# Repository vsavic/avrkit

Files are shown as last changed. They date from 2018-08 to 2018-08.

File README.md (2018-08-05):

# Cycle Alpha - AVR Programmer Board - Quick Start Guide
**AVR-based microcontroller board, designed to help in small to medium production run**.

## Board Overview

This board is designed to be a portable, stand-alone programmer tool. We can store pre-compiled HEX files on SD card and burn them on new ATMega328 MCU.

Board supports DIP and SMD version of ATMega328 MCU via ZIF28 and TQFP32 sockets. Also there’s a direct ICSP line connected to these sockets via master \ slave jumper switch configuration.

Here’s a quick summary of some of the most important parts of the board:

1. SD Card
2. 5-Way Joystick
3. Button B
4. USB
5. Button A
6. 1.8” TFT Display
7. Power Jack
8. ICSP Header
9. Slave \ Master Selector
10. TQFP-32 SMT Socket
11. ZIF28 DIP Socket

Please refer to the image below to match the numbers with the coresponding components.

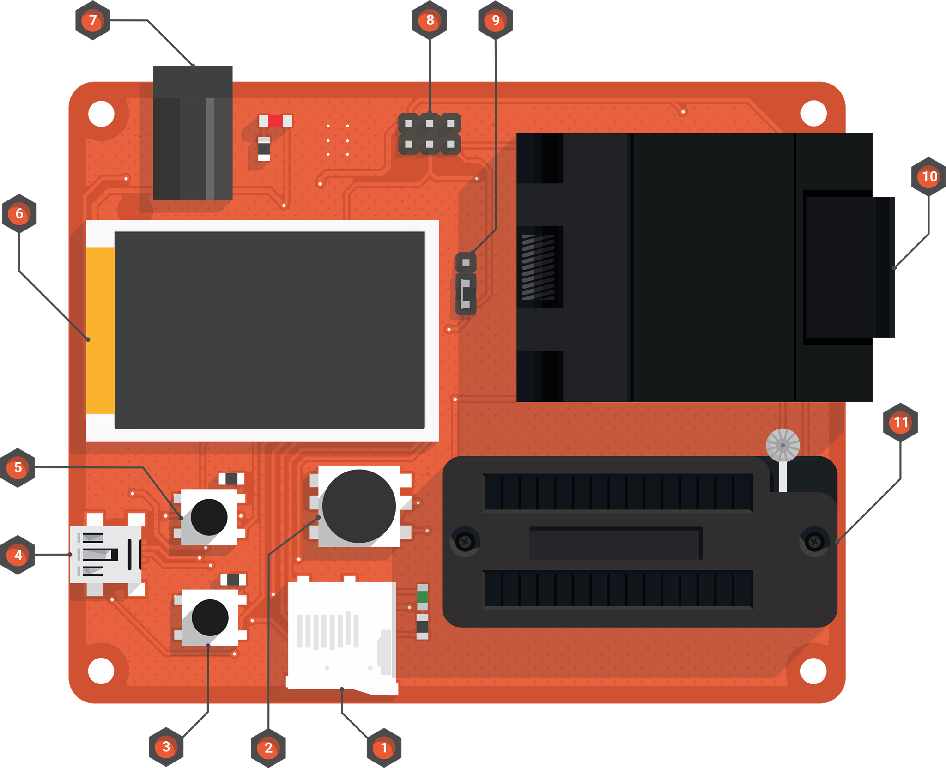
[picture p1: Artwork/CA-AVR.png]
Cycle Alpha - AVR Programmer Board


## Communcation
Board can be re-programmed via ICSP header, or directly via USB port.

It contains 1.8” TFT display which can be used with an on-board 5-way joystick in order to select the proper firmware which can be flashed on new MCU.

There’s also 2 additional buttons which are used to burn bootloader and to make a backup of the current code from the target MCU.

## Power
Board can be powered via USB cable or with external power supply battery connected to DC jack from 7 to 25 V DC. 

## Roadmap
* Add support to burn bootloader from EEPROM.
* Add support to store current target MCU firmware into EEPROM for further clonning.

At the moment, we can make a backup of the current firmware from target MCU by using "B" button on the board. Firmware will be stored on micro SD card as `Backup.hex` file.

## Notes
Common problem with some micro SD cards is that some of them cannot be initialized. In case that you get an serror screen with your SD card, follow the instruction. For more details, see `serial` console output.

SD card must be in FAT16 or FAT32 format in order to work with [SdFat](https://github.com/greiman/SdFat) library.

I tried a few different manufacturers, but the most reliable results I got with are with a Kingston 8GB class 10 micro SD card.

In case that you need to re-format your card, use this [SD Formatter](https://www.sdcard.org/downloads/formatter_4/index.html).

If you decide to modify the current firmware, keep in mind that SRAM is already very low.

Check this article for more details on [arduino memory problems](https://learn.adafruit.com/memories-of-an-arduino?view=all).

Also, here's one more really good article about [PROGMEM](http://www.gammon.com.au/progmem).

## Special Thanks

Special thanks to [Nick Gammon](https://www.gammon.com.au/contactus.htm), without him, his original project and amazing articles, this board wouldn't exist.

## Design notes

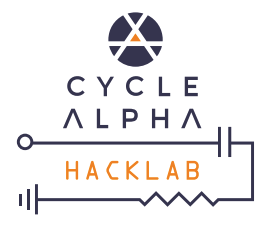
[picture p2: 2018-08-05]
Artwork/CA-HackLab.png

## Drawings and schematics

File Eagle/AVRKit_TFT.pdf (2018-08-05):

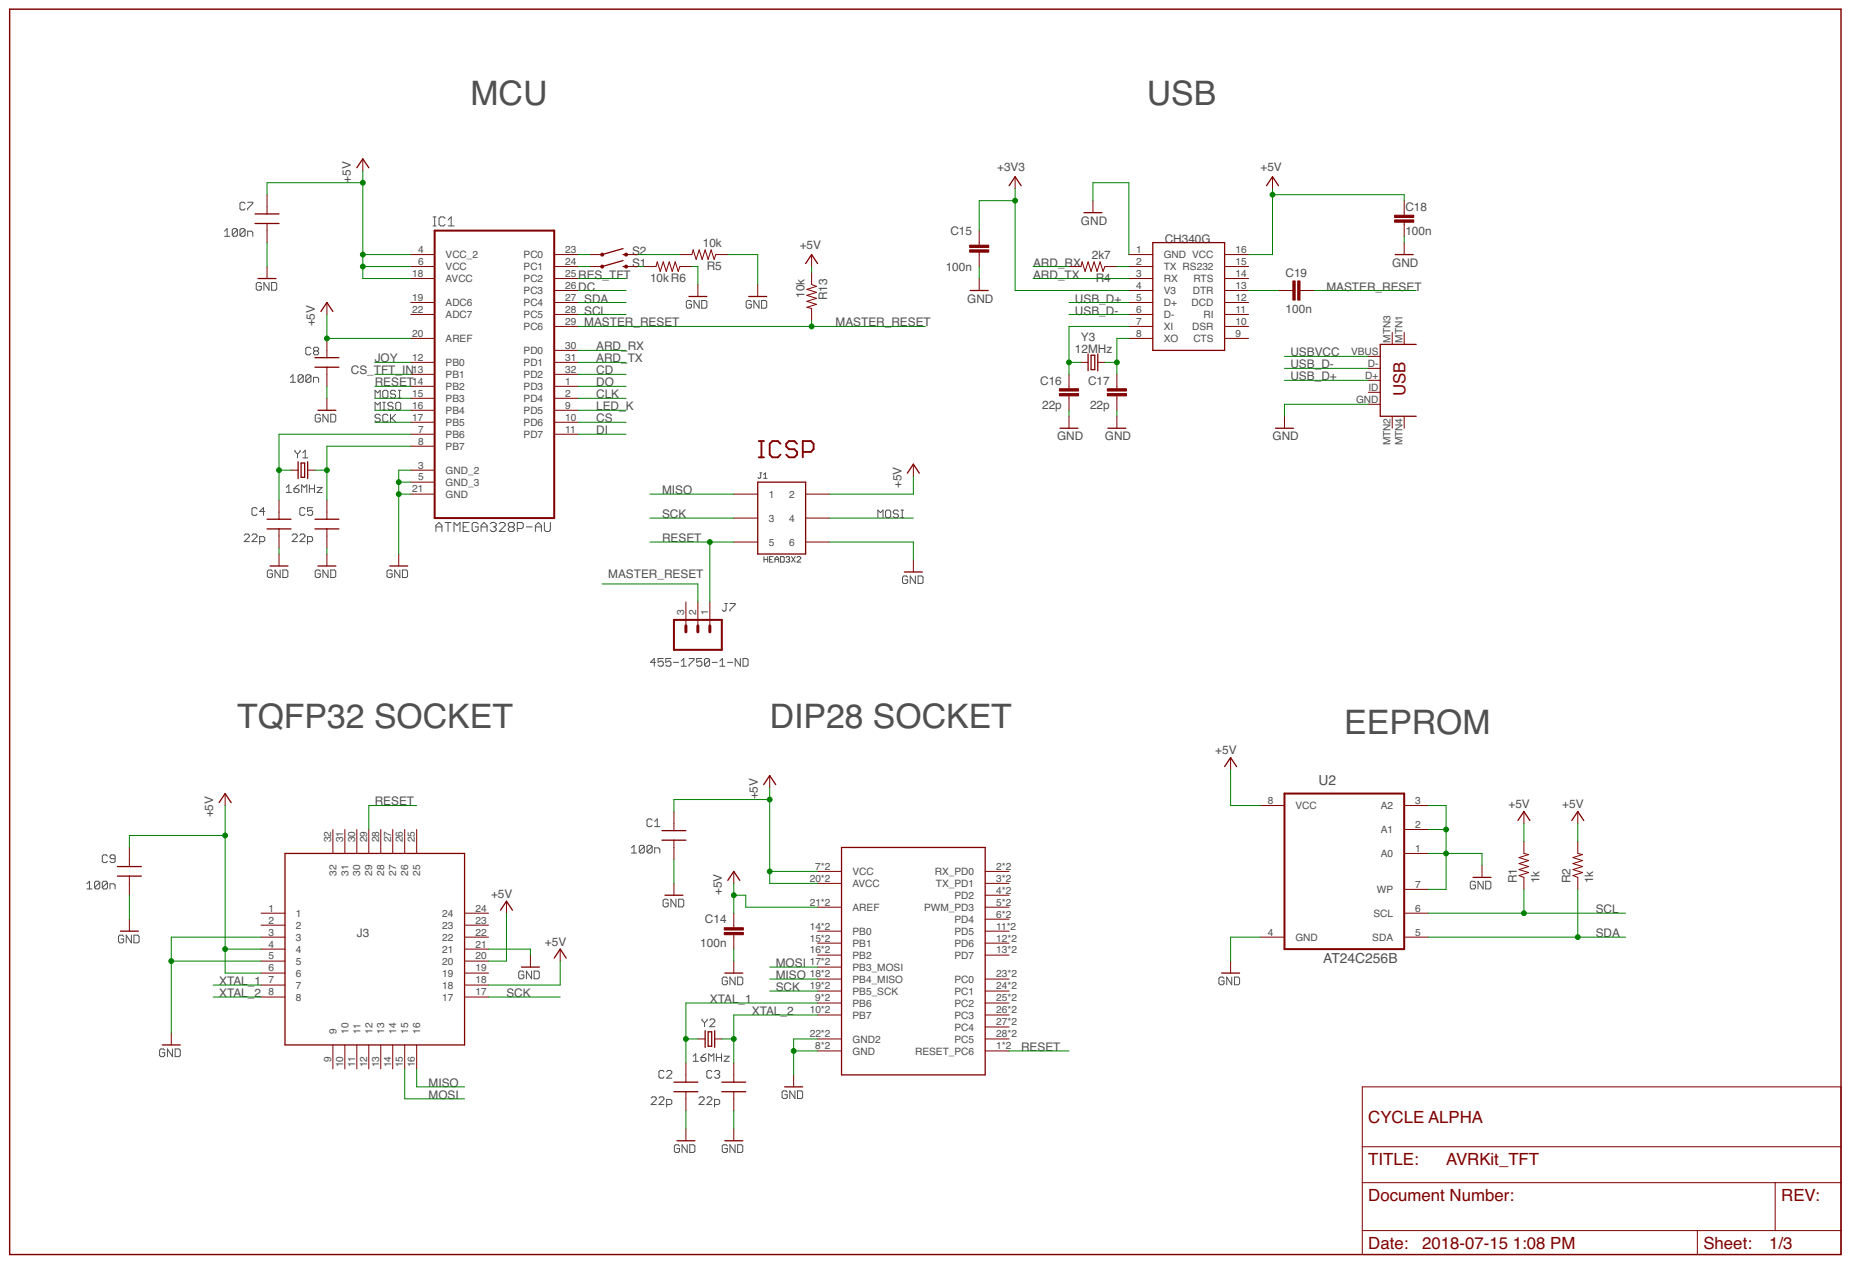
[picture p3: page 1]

REV: TITLE: Document Number: AVRKit_TFT

Date: 2018-07-15 1:08 PM | Sheet: 1/3

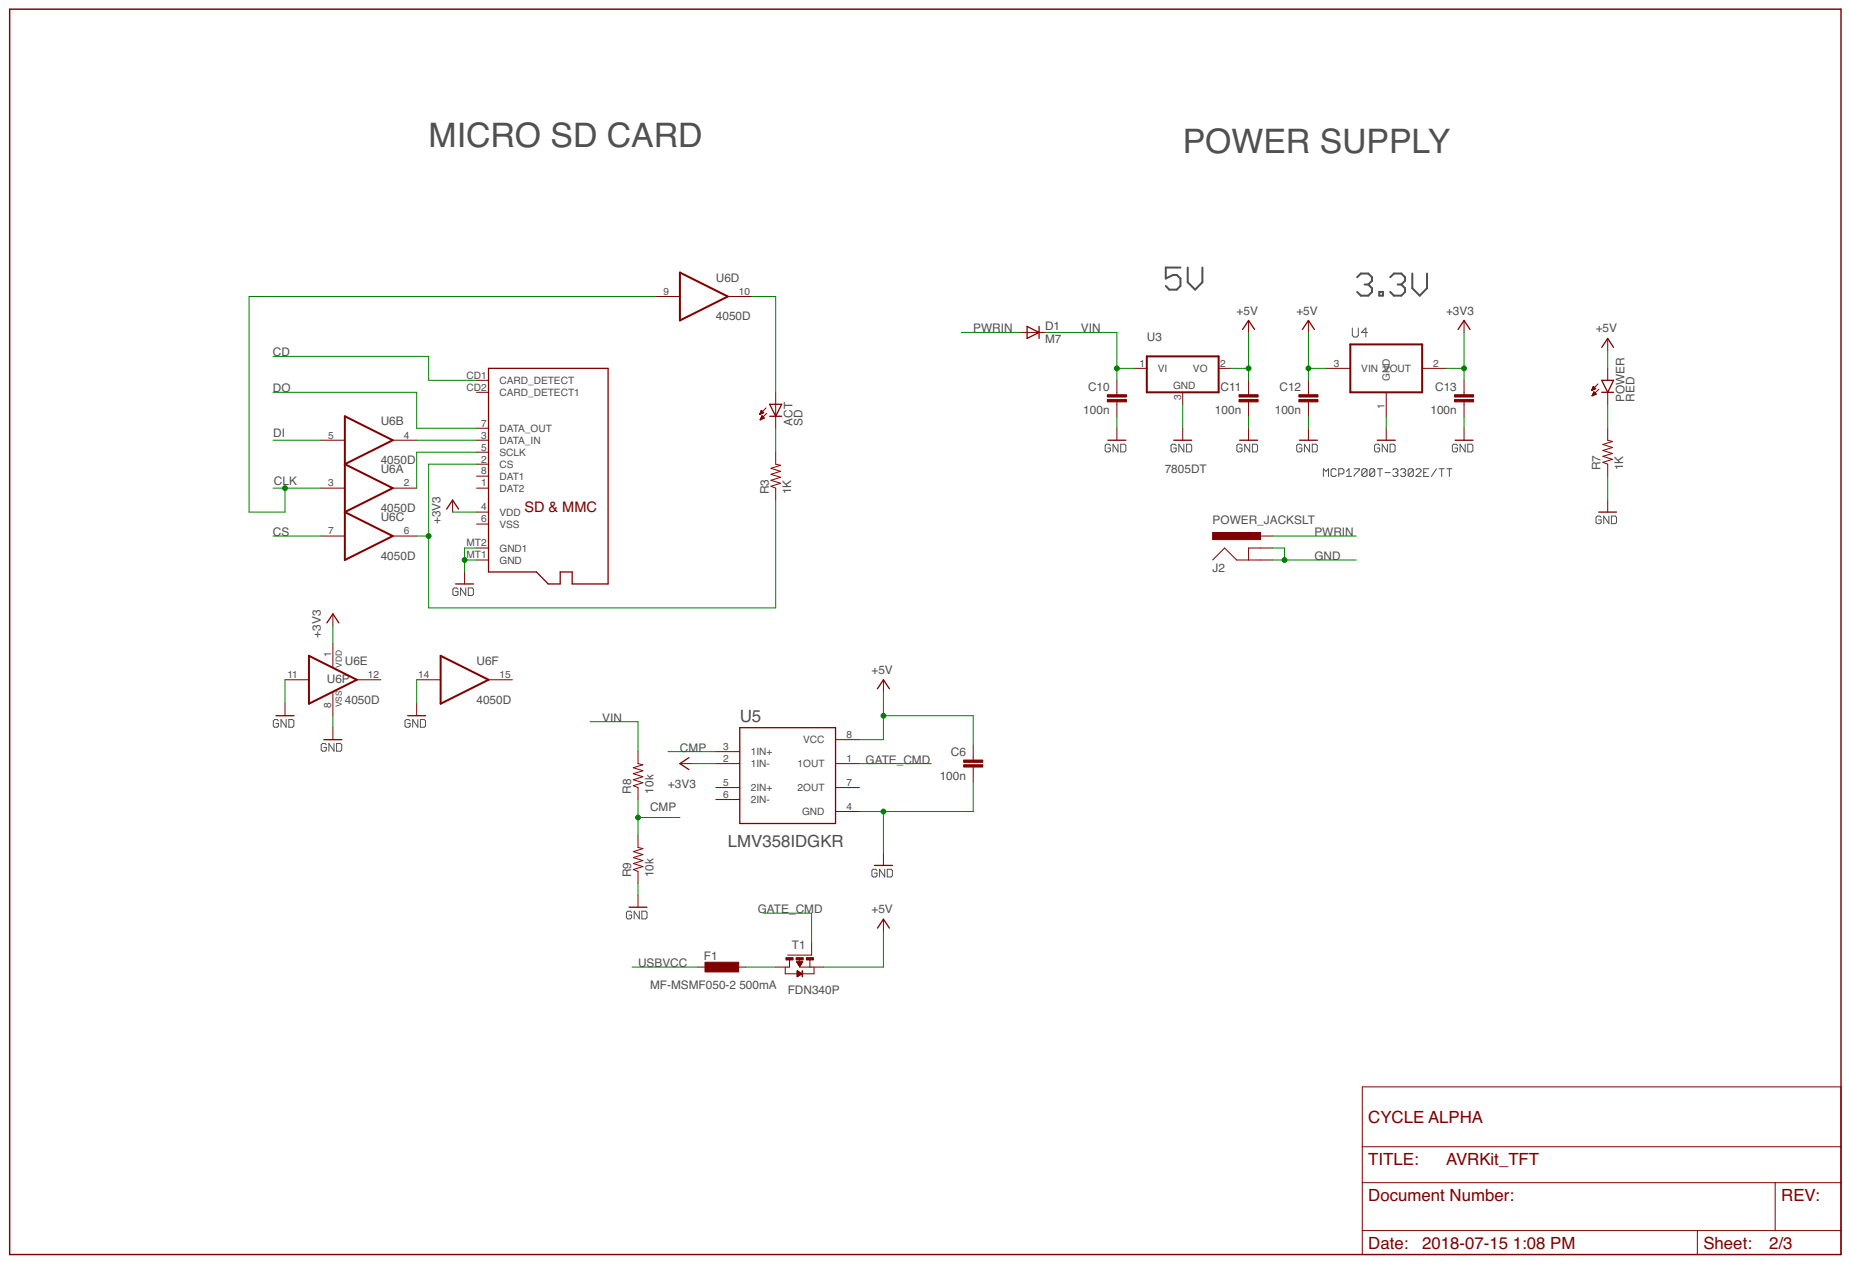
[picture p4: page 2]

REV: TITLE: Document Number: AVRKit_TFT

Date: 2018-07-15 1:08 PM | Sheet: 2/3

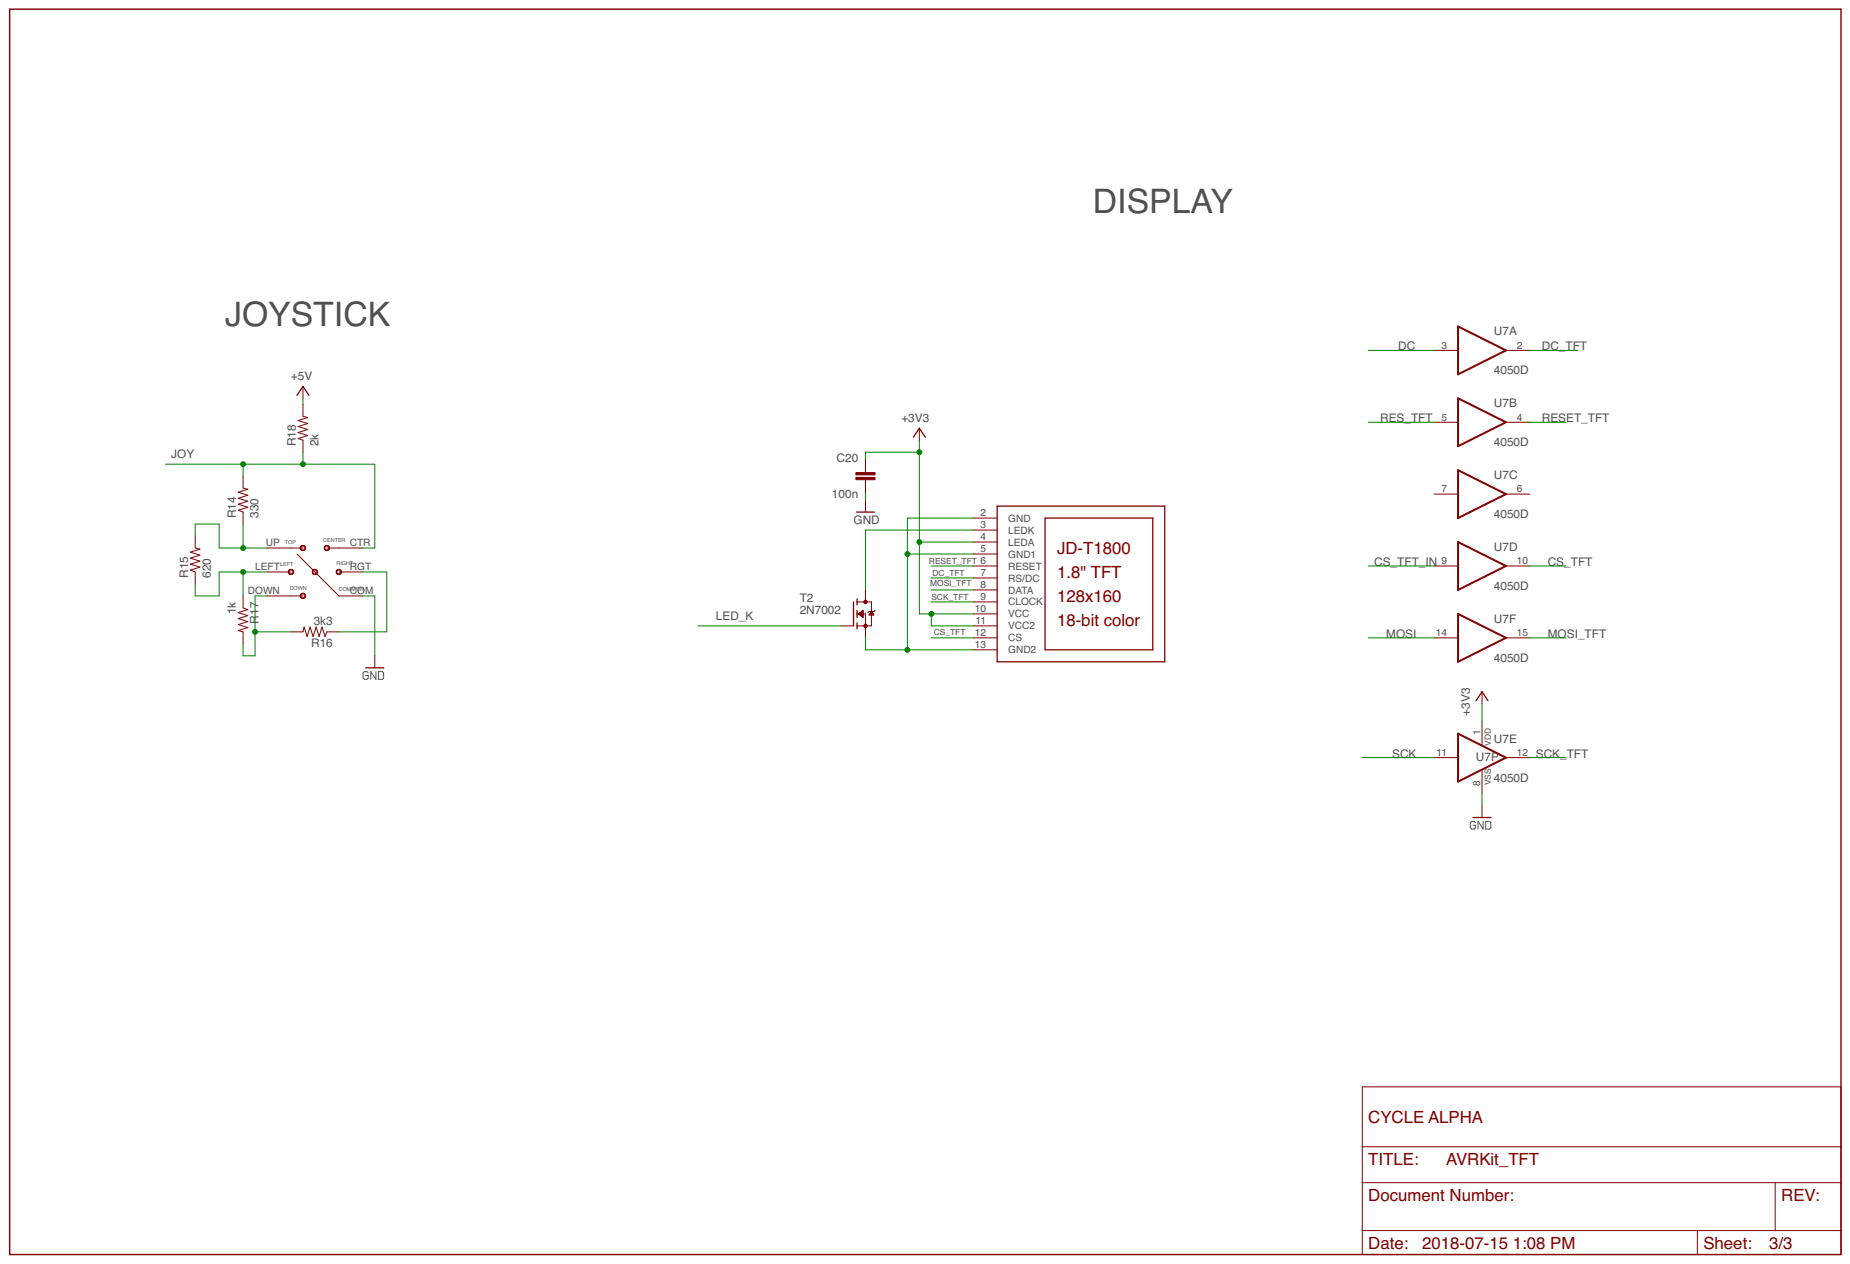
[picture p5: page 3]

REV: TITLE: Document Number: AVRKit_TFT

Date: 2018-07-15 1:08 PM | Sheet: 3/3

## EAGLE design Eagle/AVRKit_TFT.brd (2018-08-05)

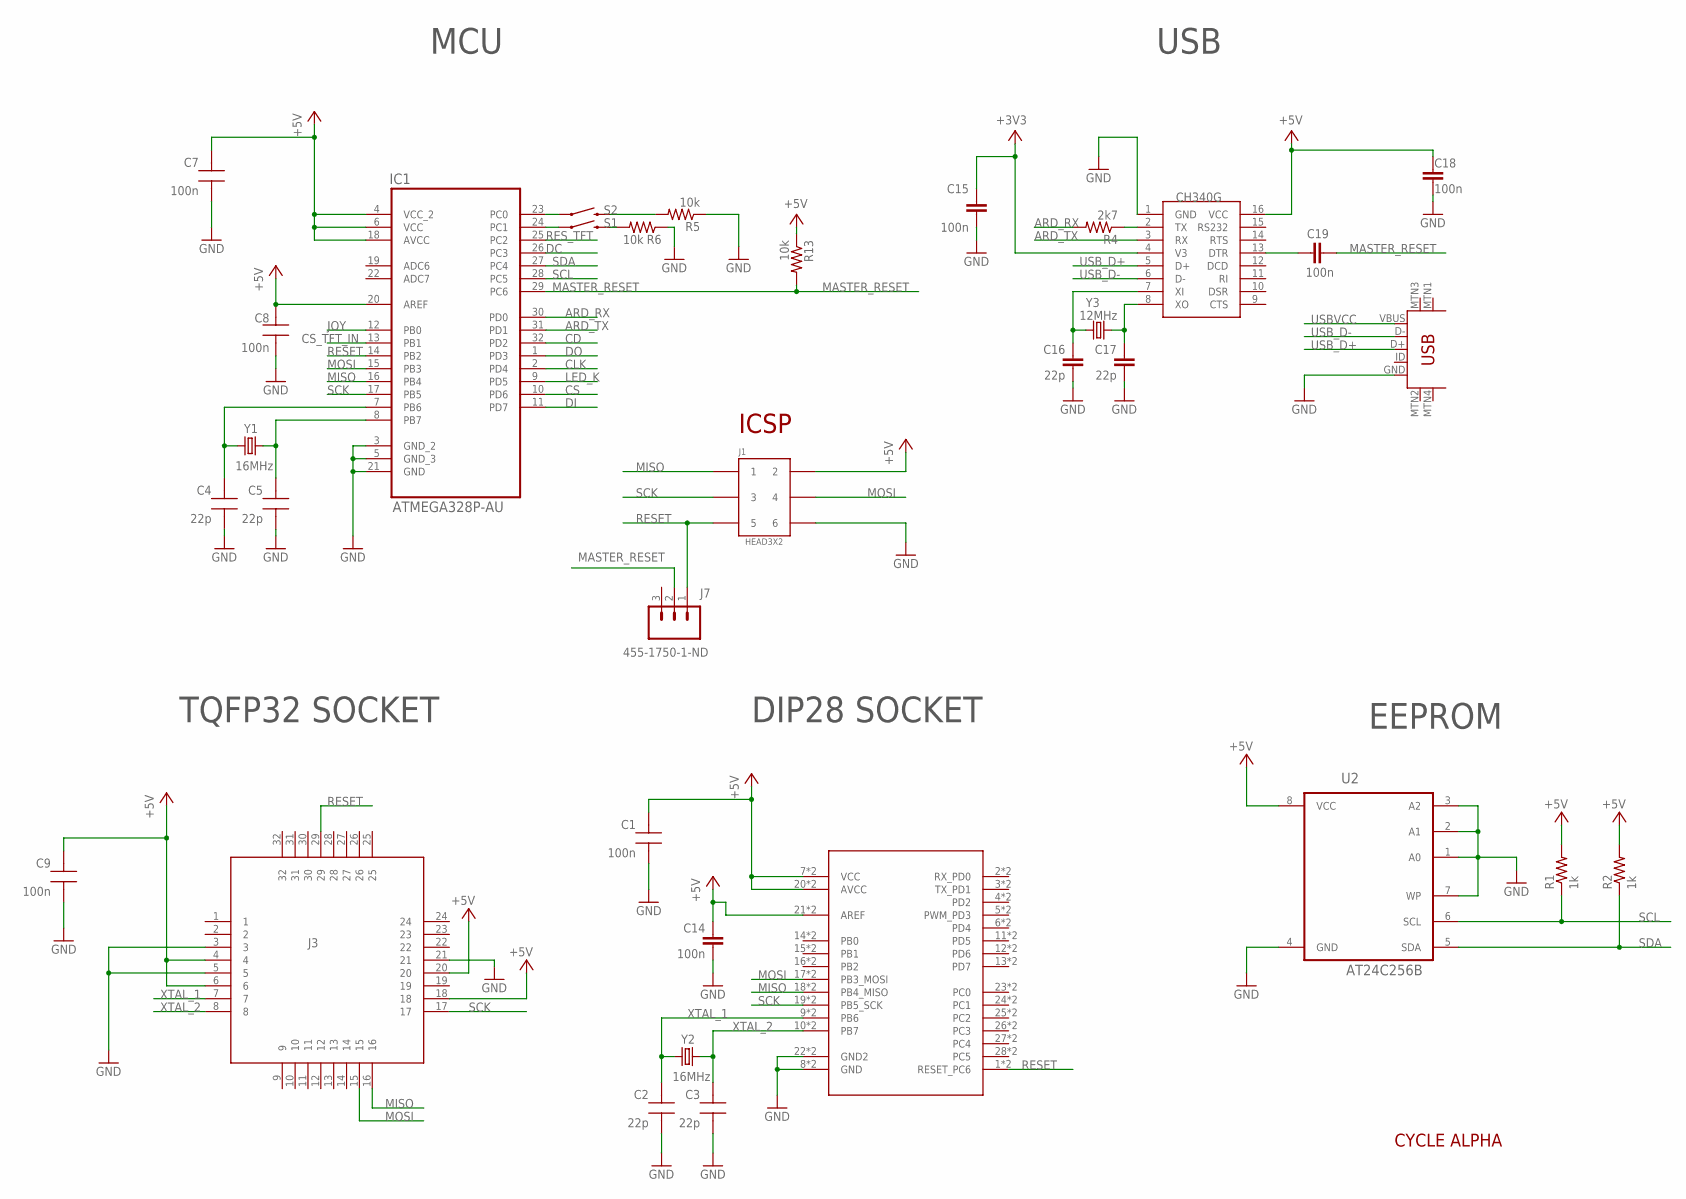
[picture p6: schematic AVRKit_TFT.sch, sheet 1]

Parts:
C1, C7, C8, C9: 100n; CAP0805-NP
C2, C3, C4, C5: 22p; CAP0805-NP
C14, C15, C18, C19: 100n; 0805
C16, C17: 22p; 0805
IC1: ATMEGA328P-AU; QFP80P900X900X120-32N
J1: HEAD3X2
J3: TQFP32_ADAPTER
J4: _ZIF28ADAPTER_2ROWS; DIL28_2ROWS
J5: USB-MINIB-5PIN; USB-MINIB
J7: 455-1750-1-ND; 1X03
R1, R2: 1k; R0805@1
R4: 2k7; R0805@1
R5, R6, R13: 10k; R0805@1
S1, S2: SWITCH-MOMENTARY-2SMD-4; TACTILE_SWITCH_TALL
U1: 0; SOIC16
U2: AT24C256B; SOIC8
Y1, Y2: 16MHz; CRYSTAL-SMD-5X3
Y3: 12MHz; CRYSTAL-SMD-5X3

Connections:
+3V3: C15.2, U1.4 (V3); also elsewhere on the board
+5V: C1.1, C7.1, C8.1, C9.1, C14.1, C18.2, IC1.4 (VCC_2), IC1.6 (VCC), IC1.18 (AVCC), IC1.20 (AREF), J1.2, J3.4, J3.6, J3.18, J3.20, J4.7 (VCC), J4.20 (AVCC), J4.21 (AREF), J4.107 (VCC), J4.120 (AVCC), J4.121 (AREF), R1.2, R2.2, R13.1, U1.16 (VCC), U2.8 (VCC); also elsewhere on the board
ARD_RX: IC1.30 (PD0), R4.2
ARD_TX: IC1.31 (PD1), U1.3 (RX)
CD: IC1.32 (PD2); also elsewhere on the board
CLK: IC1.2 (PD4); also elsewhere on the board
CS: IC1.10 (PD6); also elsewhere on the board
CS_TFT_IN: IC1.13 (PB1); also elsewhere on the board
DC: IC1.26 (PC3); also elsewhere on the board
DI: IC1.11 (PD7); also elsewhere on the board
DO: IC1.1 (PD3); also elsewhere on the board
GND: C1.2, C2.2, C3.2, C4.2, C5.2, C7.2, C8.2, C9.2, C14.2, C15.1, C16.2, C17.2, C18.1, IC1.3 (GND_2), IC1.5 (GND_3), IC1.21 (GND), J1.6, J3.3, J3.5, J3.21, J4.8 (GND), J4.22 (GND2), J4.108 (GND), J4.122 (GND2), J5.GND, R5.1, R6.1, U1.1 (GND), U2.1 (A0), U2.2 (A1), U2.3 (A2), U2.4 (GND), U2.7 (WP); also elsewhere on the board
JOY: IC1.12 (PB0); also elsewhere on the board
LED_K: IC1.9 (PD5); also elsewhere on the board
MASTER_RESET: C19.1, IC1.29 (PC6), J7.2, R13.2
MISO: IC1.16 (PB4), J1.1, J3.16, J4.18 (PB4_MISO), J4.118 (PB4_MISO)
MOSI: IC1.15 (PB3), J1.4, J3.15, J4.17 (PB3_MOSI), J4.117 (PB3_MOSI); also elsewhere on the board
unnamed: IC1.23 (PC0), S2.A2 (1)
unnamed: IC1.24 (PC1), S1.A2 (1)
unnamed: R5.2, S2.B2 (2)
unnamed: R6.2, S1.B2 (2)
unnamed: C19.2, U1.13 (DTR)
unnamed: R4.1, U1.2 (TX)
OSC3: C4.1, IC1.7 (PB6), Y1.3 (2)
OSC4: C5.1, IC1.8 (PB7), Y1.1
RESET: IC1.14 (PB2), J1.5, J3.29, J4.1 (RESET_PC6), J4.101 (RESET_PC6), J7.1
RES_TFT: IC1.25 (PC2); also elsewhere on the board
SCK: IC1.17 (PB5), J1.3, J3.17, J4.19 (PB5_SCK), J4.119 (PB5_SCK); also elsewhere on the board
SCL: IC1.28 (PC5), R1.1, U2.6 (SCL)
SDA: IC1.27 (PC4), R2.1, U2.5 (SDA)
USBVCC: J5.VBUS; also elsewhere on the board
USB_D+: J5.D+, U1.5 (D+)
USB_D-: J5.D-, U1.6 (D-)
XI1: C16.1, U1.7 (XI), Y3.1
XO1: C17.1, U1.8 (XO), Y3.3 (2)
XTAL_1: C2.1, J3.7, J4.9 (PB6), J4.109 (PB6), Y2.3 (2)
XTAL_2: C3.1, J3.8, J4.10 (PB7), J4.110 (PB7), Y2.1

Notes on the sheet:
USB
DIP28 SOCKET
MCU
EEPROM
TQFP32 SOCKET
ICSP
CYCLE ALPHA

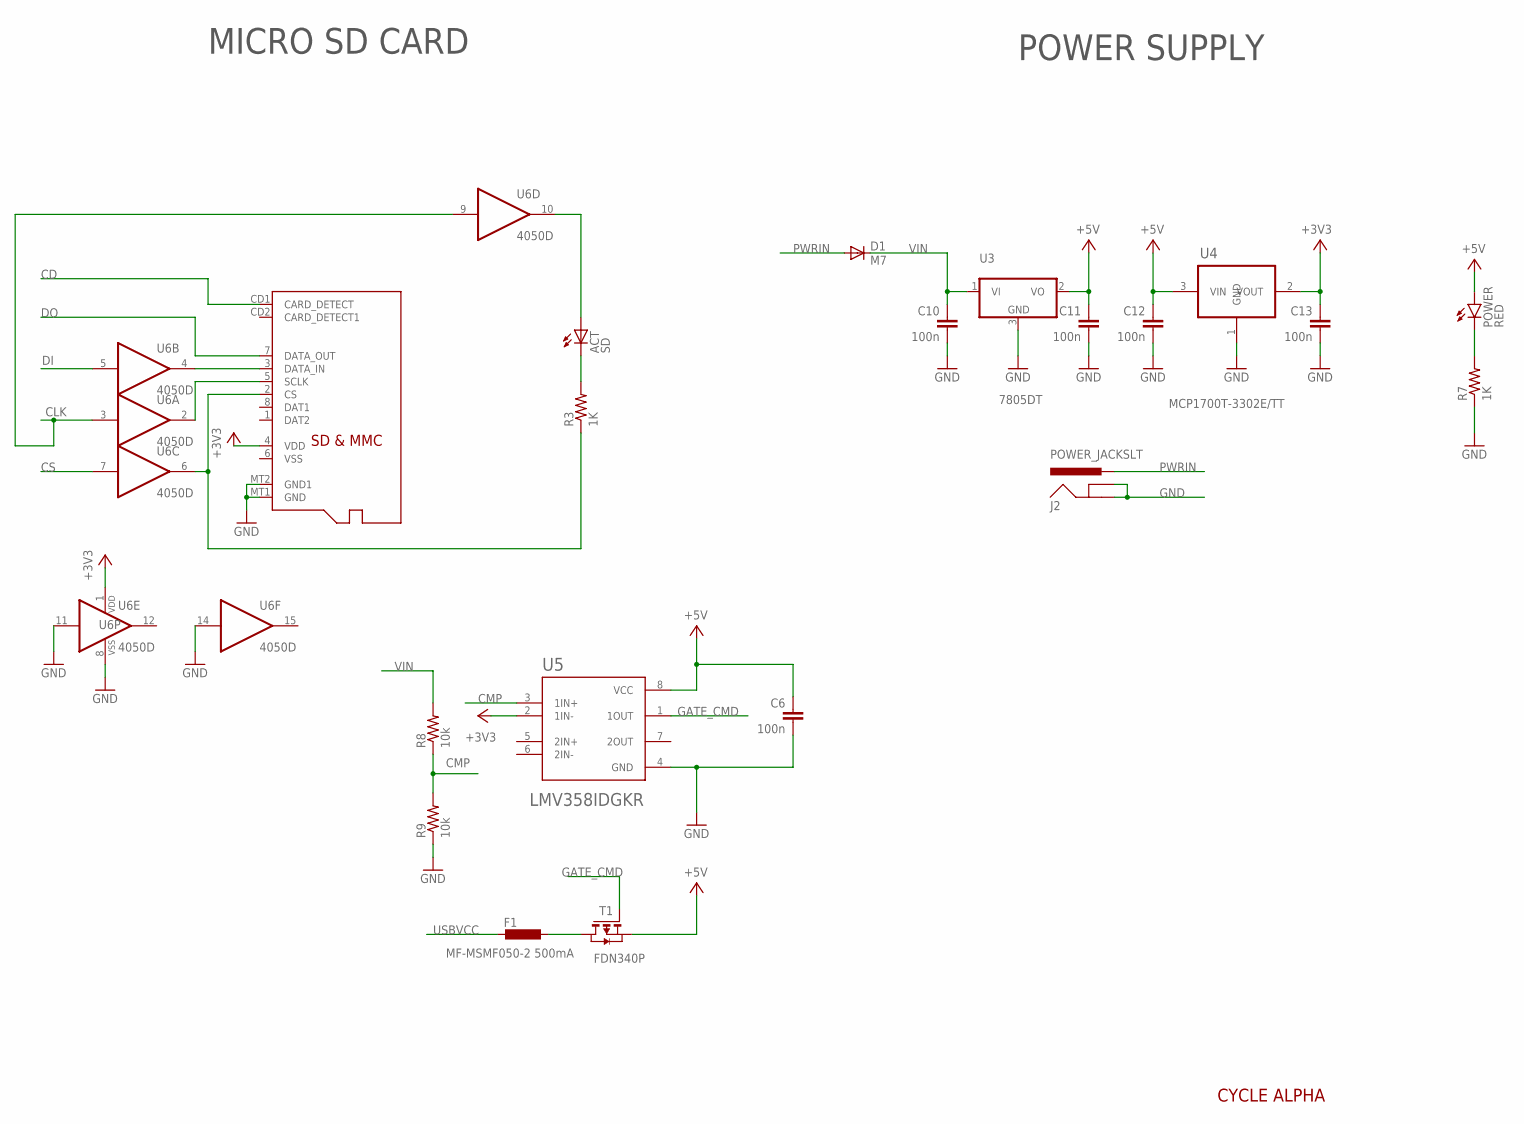
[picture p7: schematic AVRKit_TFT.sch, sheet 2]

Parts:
ACT: SD; CHIP-LED0805
C6, C10, C11, C12, C13: 100n; 0805
D1: M7; SMB
F1: MF-MSMF050-2 500mA; L1812
J2: POWER_JACKSLT; POWER_JACK_SLOT
J6: MICROSD_FOOTPRINT_2
POWER: RED; LED-1206
R3, R7: 1K; R0805
R8, R9: 10k; R0805
T1: FDN340P; SOT-23
U3: 7805DT; TO252
U4: MCP1700T-3302E/TT; SOT95P237X112-3N
U5: LMV358IDGKR; SOP65P490X110-8N
U6: 4050D; SO16

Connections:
+3V3: C13.1, J6.4 (VDD), U4.2 (VOUT), U5.2 (1IN-), U6.1 (VDD); also elsewhere on the board
+5V: C6.1, C11.1, C12.1, POWER.A, T1.2 (S), U3.2 (VO), U4.3 (VIN), U5.8 (VCC); also elsewhere on the board
CD: J6.CD1 (CARD_DETECT); also elsewhere on the board
CLK: U6.3 (I), U6.9 (I); also elsewhere on the board
CMP: R8.1, R9.2, U5.3 (1IN+)
CS: U6.7 (I); also elsewhere on the board
DI: U6.5 (I); also elsewhere on the board
DO: J6.7 (DATA_OUT); also elsewhere on the board
GATE_CMD: T1.3 (G), U5.1 (1OUT)
GND: C6.2, C10.2, C11.2, C12.2, C13.2, J2.GND@1 (GNDBREAK), J2.GND@2 (GND), J6.MT1 (GND), J6.MT2 (GND1), R7.1, R9.1, U3.3 (GND), U4.1 (GND), U5.4 (GND), U6.8 (VSS), U6.11 (I), U6.14 (I); also elsewhere on the board
unnamed: ACT.A, U6.10 (O)
unnamed: J6.5 (SCLK), U6.2 (O)
unnamed: J6.2 (CS), R3.1, U6.6 (O)
unnamed: ACT.C, R3.2
unnamed: J6.3 (DATA_IN), U6.4 (O)
unnamed: POWER.C, R7.2
unnamed: F1.1, T1.1 (D)
PWRIN: D1.A, J2.PWR
USBVCC: F1.2; also elsewhere on the board
VIN: C10.1, D1.C, R8.2, U3.1 (VI)

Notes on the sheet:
MICRO SD CARD
POWER SUPPLY
CYCLE ALPHA

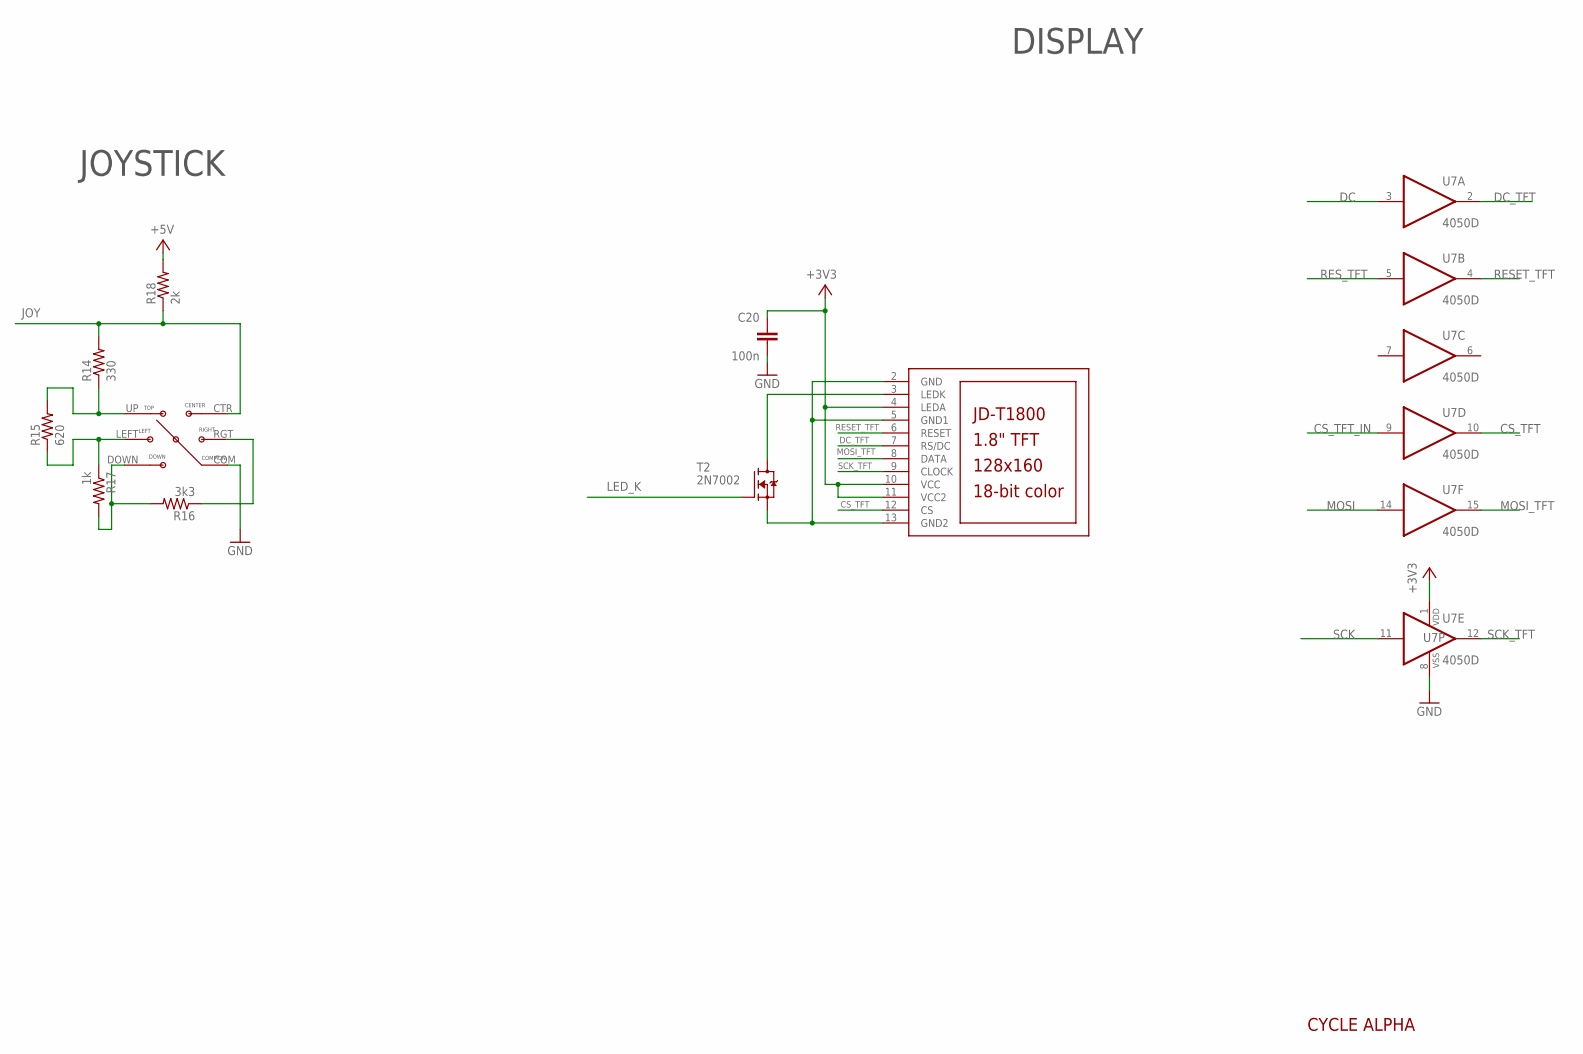
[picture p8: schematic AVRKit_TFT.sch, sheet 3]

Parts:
C20: 100n; 0805
LCD1: JD-T1800
R14: 330; R0805
R15: 620; R0805
R16: 3k3; R0805
R17: 1k; R0805
R18: 2k; R0805
T2: 2N7002; SOT23
U7: 4050D; SO16
U$3: JOG-SWITCH-5-WAY-SMD; JOG-SWITCH-10MM-SMD

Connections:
+3V3: C20.2, LCD1.4 (LEDA), LCD1.10 (VCC), LCD1.11 (VCC2), U7.1 (VDD); also elsewhere on the board
+5V: R18.2; also elsewhere on the board
CS_TFT: LCD1.12 (CS), U7.10 (O)
CS_TFT_IN: U7.9 (I); also elsewhere on the board
DC: U7.3 (I); also elsewhere on the board
DC_TFT: LCD1.7 (RS/DC), U7.2 (O)
GND: C20.1, LCD1.2 (GND), LCD1.5 (GND1), LCD1.13 (GND2), T2.2 (S), U7.8 (VSS), U$3.COM; also elsewhere on the board
JOY: R14.2, R18.1, U$3.CTR; also elsewhere on the board
LED_K: T2.1 (G); also elsewhere on the board
MOSI: U7.14 (I); also elsewhere on the board
MOSI_TFT: LCD1.8 (DATA), U7.15 (O)
unnamed: LCD1.3 (LEDK), T2.3 (D)
unnamed: R14.1, R15.2, U$3.UP
unnamed: R15.1, R17.1, U$3.LEFT
unnamed: R16.2, R17.2, U$3.DOWN
unnamed: R16.1, U$3.RGT
RESET_TFT: LCD1.6 (RESET), U7.4 (O)
RES_TFT: U7.5 (I); also elsewhere on the board
SCK: U7.11 (I); also elsewhere on the board
SCK_TFT: LCD1.9 (CLOCK), U7.12 (O)

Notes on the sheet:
JOYSTICK
DISPLAY
CYCLE ALPHA

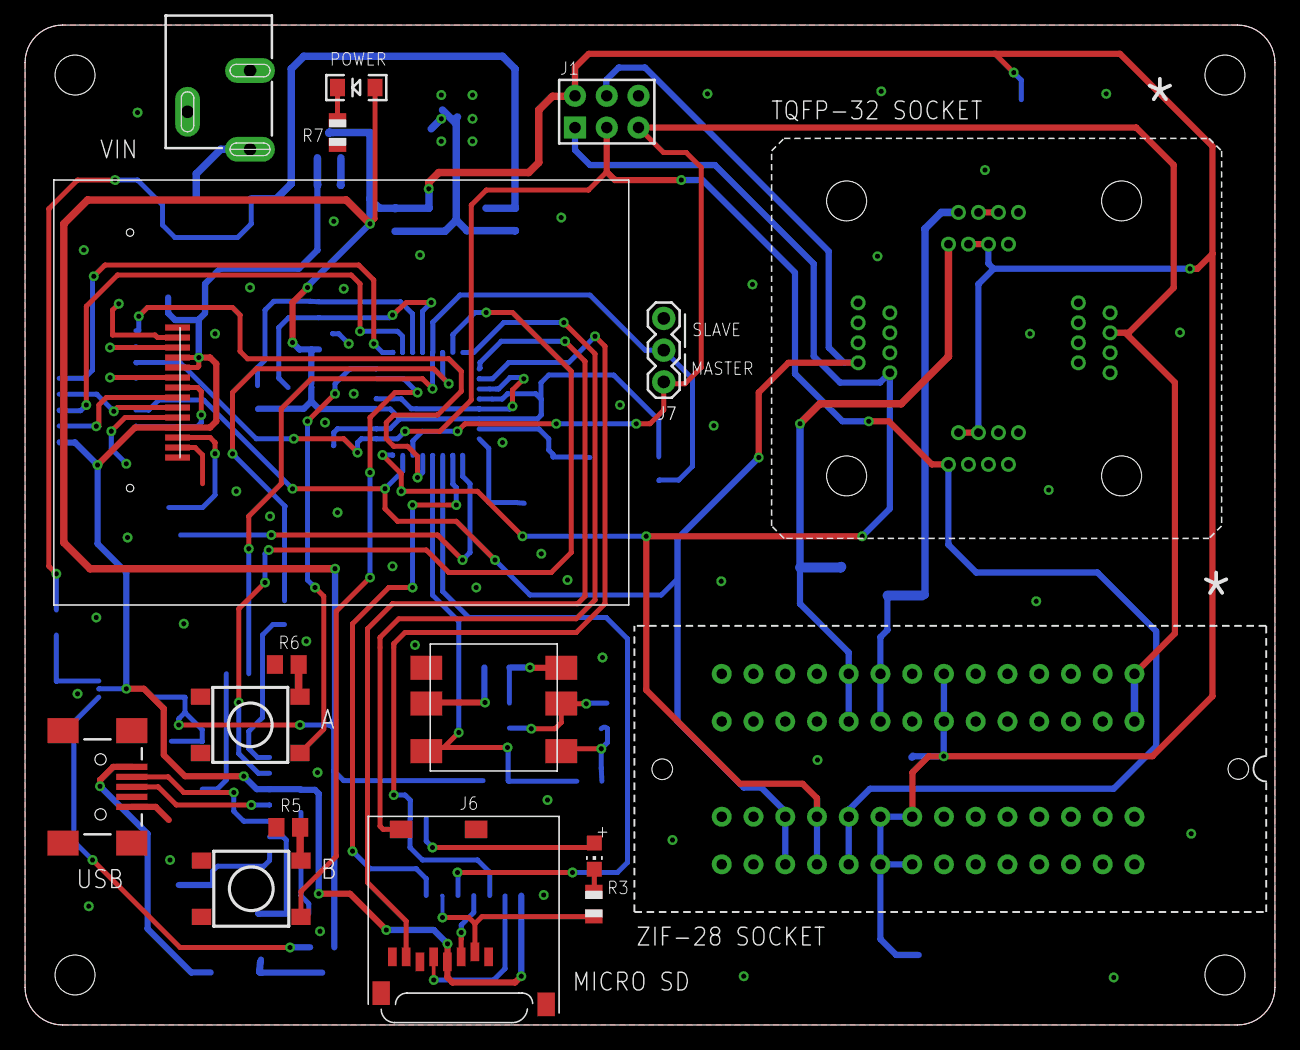
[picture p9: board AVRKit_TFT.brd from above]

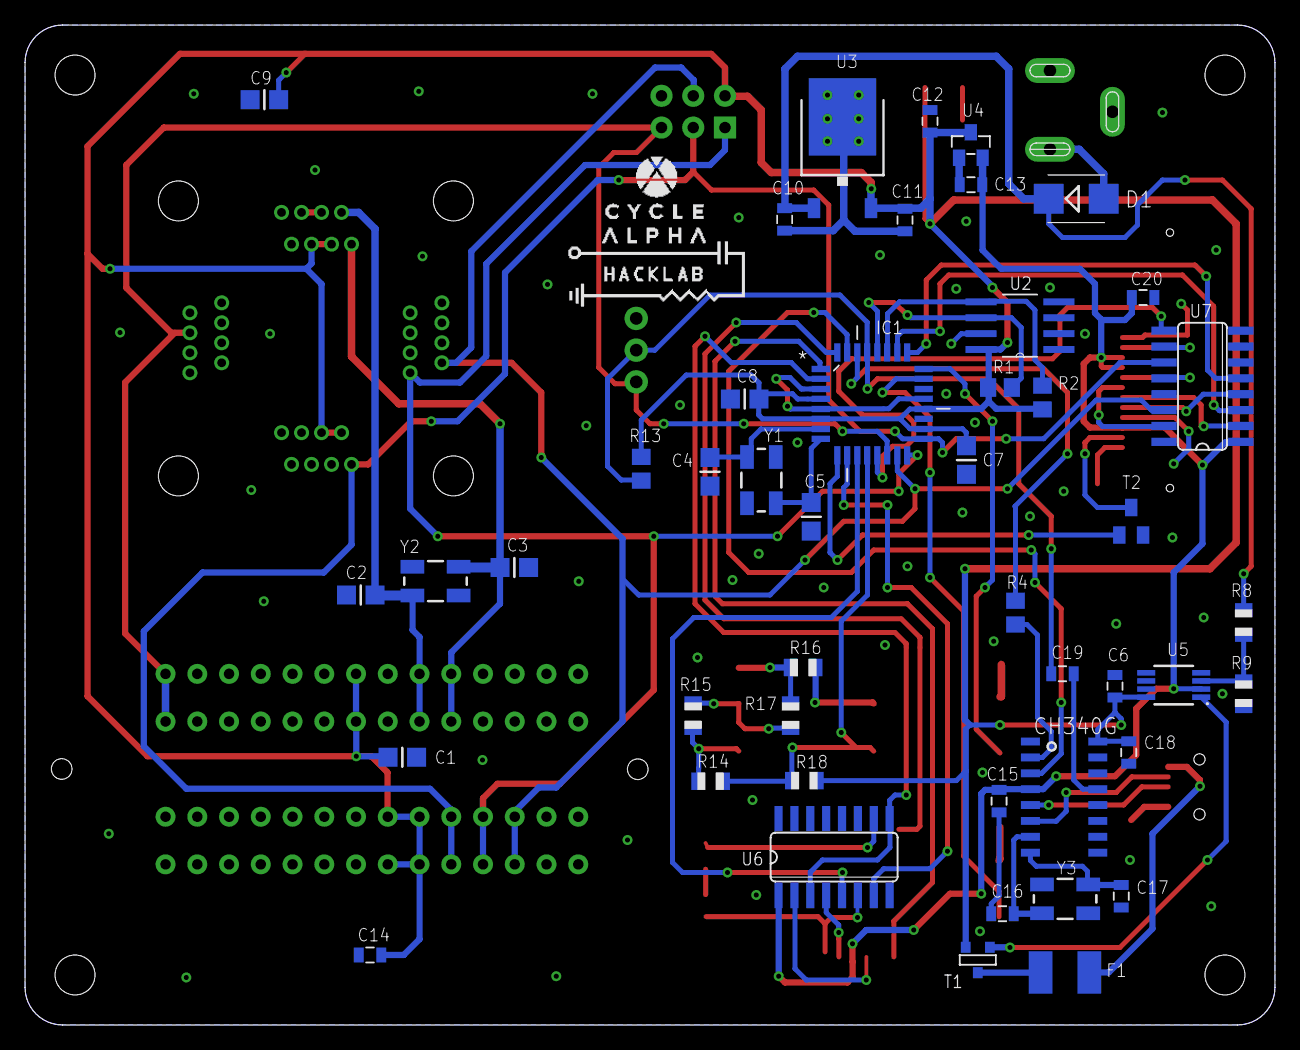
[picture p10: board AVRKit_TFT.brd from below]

Board: 2 copper layers, 100.0 x 80.0 mm, 64 parts (47 on the bottom side), 58 nets.

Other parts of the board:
U$4: LOGO_CYCLE_ALPHA_HACKLAB_14X12_MM

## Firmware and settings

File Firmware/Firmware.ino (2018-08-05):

// Original Author: Nick Gammon

// Modified by Vladica Savic

/*
 For original project idea, details, photos, wiring, instructions, see:
    http://www.gammon.com.au/forum/?id=11638
 Copyright 2012 Nick Gammon.
 
 
 PERMISSION TO DISTRIBUTE
 
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
 
 LIMITATION OF LIABILITY
 
 The software is provided "as is", without warranty of any kind, express or implied, 
 including but not limited to the warranties of merchantability, fitness for a particular 
 purpose and noninfringement. In no event shall the authors or copyright holders be liable 
 for any claim, damages or other liability, whether in an action of contract, 
 tort or otherwise, arising from, out of or in connection with the software 
 or the use or other dealings in the software. 
*/

#include <SdFatConfig.h>
#include <SdFat.h>
#include <SysCall.h>
#include <Adafruit_GFX.h>    
#include <Adafruit_ST7735.h> 
#include <SPI.h>
#include <Wire.h> 
#include "SdFat.h"

#define EEPROM_ADDRESS 0x50    //Address of 24LC256 eeprom chip  

#define TFT_CS    9
#define TFT_RST   A2     
#define TFT_DC    A3
#define TFT_SCLK  13   
#define TFT_MOSI  11   
#define TFT_LED   5

Adafruit_ST7735 tft = Adafruit_ST7735(TFT_CS, TFT_DC, TFT_RST);

#define JOYSTICK_KEY  A6

const PROGMEM bool allowTargetToRun = true;  // if true, programming lines are freed when not programming

// A and B switches, A to burn bootloader, B to backup current (target) MCU firmware
const PROGMEM byte switchA = A1;
const PROGMEM byte switchB = A0;


// status "messages"
typedef enum { 
  MSG_LINE_TOO_LONG,       // line on disk too long to read
  MSG_LINE_TOO_SHORT,      // line too short to be valid
  MSG_LINE_DOES_NOT_START_WITH_COLON,  // line does not start with a colon
  MSG_INVALID_HEX_DIGITS,  // invalid hex where there should be hex
  MSG_BAD_SUMCHECK,        // line fails sumcheck
  MSG_LINE_NOT_EXPECTED_LENGTH,  // record not length expected
  MSG_UNKNOWN_RECORD_TYPE,  // record type not known
  MSG_NO_END_OF_FILE_RECORD,  // no 'end of file' at end of file
  MSG_FILE_TOO_LARGE_FOR_FLASH,  // file will not fit into flash
  MSG_CANNOT_OPEN_FILE, // cannot open file

  MSG_CANNOT_ENTER_PROGRAMMING_MODE,  // cannot program target chip
  MSG_NO_BOOTLOADER_FUSE,             // chip does not have bootloader
  MSG_CANNOT_FIND_SIGNATURE,      // cannot find chip signature
  MSG_UNRECOGNIZED_SIGNATURE,     // signature not known
  MSG_BAD_START_ADDRESS,          // file start address invalid
  MSG_VERIFICATION_ERROR,         // verification error after programming
  MSG_FLASHED_OK,                 // flashed OK
 } msgType;

const PROGMEM unsigned int ENTER_PROGRAMMING_ATTEMPTS = 2;

// Atmega328 --> [[[[[ PINS ARE REPLACED TO USE "REGULAR" PINS (13, 12, 11, 10) ]]]]]
const PROGMEM byte MSPIM_SCK = 13;  // port B bit 5
const PROGMEM byte BB_MISO   = 12;  // port B bit 4
const PROGMEM byte BB_MOSI = 11;    // port B bit 3
const PROGMEM byte MSPIM_SS  = 10;  // port B bit 2

/*

Connect target processor like this:

  D4: (SCK)   --> SCK as per datasheet        [[[[[[[ 13 ]]]]]]
  D5: (SS)    --> goes to /RESET on target    [[[[[[[ 10 ]]]]]]
  D6: (MISO)  --> MISO as per datasheet       [[[[[[[ 12 ]]]]]]
  D7: (MOSI)  --> MOSI as per datasheet       [[[[[[[ 11 ]]]]]]
  
  D9: 8 Mhz clock signal if required by target 9
*/

// Atmega328
  #define BB_MISO_PORT PINB
  #define BB_MOSI_PORT PORTB
  #define BB_SCK_PORT PORTB
  const PROGMEM byte BB_SCK_BIT = 5;  // pin 13
  const PROGMEM byte BB_MISO_BIT = 4; // pin 12
  const PROGMEM byte BB_MOSI_BIT = 3; // pin 11

// control speed of programming
const PROGMEM byte BB_DELAY_MICROSECONDS = 6;

// target board reset goes to here
const PROGMEM byte RESET = MSPIM_SS;

const PROGMEM unsigned long NO_PAGE = 0xFFFFFFFF;
const PROGMEM int MAX_FILENAME = 13;

const PROGMEM uint8_t SOFT_MISO_PIN = 3;
const PROGMEM uint8_t SOFT_MOSI_PIN = 7;
const PROGMEM uint8_t SOFT_SCK_PIN  = 4;
const PROGMEM uint8_t SD_CHIP_SELECT_PIN = 6;

SdFatSoftSpi<SOFT_MISO_PIN, SOFT_MOSI_PIN, SOFT_SCK_PIN> SD;

SdFile file;

char * selectedHexFile;

// actions to take
enum {
    checkFile,
    verifyFlash,
    writeToFlash,
};

// copy of fuses/lock bytes found for this processor
byte fuses [5];

// meaning of bytes in above array
enum {
      lowFuse,
      highFuse,
      extFuse,
      lockByte,
      calibrationByte
};

// structure to hold signature and other relevant data about each chip
typedef struct {
   byte sig [3];
   const char * desc;
   unsigned long flashSize;
   unsigned int baseBootSize;
   unsigned long pageSize;     // bytes
   byte fuseWithBootloaderSize;  // ie. one of: lowFuse, highFuse, extFuse
   byte timedWrites;    // if pollUntilReady won't work by polling the chip
} signatureType;

const unsigned long kb = 1024;
const byte NO_FUSE = 0xFF;


// see Atmega datasheets
const signatureType signatures [] PROGMEM = 
  {
//     signature        description   flash size   bootloader  flash  fuse
//                                                     size    page    to
//                                                             size   change

  // Atmega328 family
  { { 0x1E, 0x95, 0x0F }, "ATmega328P",  32 * kb,       512,   128,  highFuse },


  };  // end of signatures
       
// number of items in an array
#define NUMITEMS(arg) ((unsigned int) (sizeof (arg) / sizeof (arg [0])))

// programming commands to send via SPI to the chip
enum {
    progamEnable = 0xAC,
    
      // writes are preceded by progamEnable
      chipErase = 0x80,
      writeLockByte = 0xE0,
      writeLowFuseByte = 0xA0,
      writeHighFuseByte = 0xA8,
      writeExtendedFuseByte = 0xA4,
    
    pollReady = 0xF0,
    
    programAcknowledge = 0x53,
    
    readSignatureByte = 0x30,
    readCalibrationByte = 0x38,
    
    readLowFuseByte = 0x50,       readLowFuseByteArg2 = 0x00,
    readExtendedFuseByte = 0x50,  readExtendedFuseByteArg2 = 0x08,
    readHighFuseByte = 0x58,      readHighFuseByteArg2 = 0x08,  
    readLockByte = 0x58,          readLockByteArg2 = 0x00,  
    
    readProgramMemory = 0x20,  
    writeProgramMemory = 0x4C,
    loadExtendedAddressByte = 0x4D,
    loadProgramMemory = 0x40,
    
};  // end of enum

// which program instruction writes which fuse
const byte fuseCommands [4] = { writeLowFuseByte, writeHighFuseByte, writeExtendedFuseByte, writeLockByte };

// types of record in .hex file
enum {
    hexDataRecord,  // 00
    hexEndOfFile,   // 01
    hexExtendedSegmentAddressRecord, // 02
    hexStartSegmentAddressRecord,  // 03
    hexExtendedLinearAddressRecord, // 04
    hexStartLinearAddressRecord // 05
};


void ShowMessage (const byte which)
  {
  
  // now flash an appropriate sequence
  switch (which)
     {
      // problems reading the .hex file
      case MSG_LINE_TOO_LONG:                   Serial.println(F("MSG_LINE_TOO_LONG")); break;
      case MSG_LINE_TOO_SHORT:                  Serial.println(F("MSG_LINE_TOO_SHORT")); break;
      case MSG_LINE_DOES_NOT_START_WITH_COLON:  Serial.println(F("MSG_LINE_DOES_NOT_START_WITH_COLON")); break;
      case MSG_INVALID_HEX_DIGITS:              Serial.println(F("MSG_INVALID_HEX_DIGITS")); break;
      case MSG_BAD_SUMCHECK:                    Serial.println(F("MSG_BAD_SUMCHECK")); break;
      case MSG_LINE_NOT_EXPECTED_LENGTH:        Serial.println(F("MSG_LINE_NOT_EXPECTED_LENGTH")); break;
      case MSG_UNKNOWN_RECORD_TYPE:             Serial.println(F("MSG_UNKNOWN_RECORD_TYPE")); break;
      case MSG_NO_END_OF_FILE_RECORD:           Serial.println(F("MSG_NO_END_OF_FILE_RECORD")); break;
      
      // problems with the file contents
      case MSG_FILE_TOO_LARGE_FOR_FLASH:        Serial.println(F("MSG_FILE_TOO_LARGE_FOR_FLASH")); break;
      case MSG_CANNOT_OPEN_FILE:                Serial.println(F("MSG_CANNOT_OPEN_FILE")); break;
      
      // problems programming the chip
      case MSG_CANNOT_ENTER_PROGRAMMING_MODE:  Serial.println(F("MSG_CANNOT_ENTER_PROGRAMMING_MODE")); break;
      case MSG_NO_BOOTLOADER_FUSE:             Serial.println(F("MSG_NO_BOOTLOADER_FUSE")); break;
      case MSG_CANNOT_FIND_SIGNATURE:          Serial.println(F("MSG_CANNOT_FIND_SIGNATURE")); break;
      case MSG_UNRECOGNIZED_SIGNATURE:         Serial.println(F("MSG_UNRECOGNIZED_SIGNATURE")); break;
      case MSG_BAD_START_ADDRESS:              Serial.println(F("MSG_BAD_START_ADDRESS")); break;
      case MSG_VERIFICATION_ERROR:             Serial.println(F("MSG_VERIFICATION_ERROR")); break;
      case MSG_FLASHED_OK:                     Serial.println(F("MSG_FLASHED_OK")); break;
      
     default:                                  Serial.println(F("UNKNOWN_ERROR"));  break;   // unknown error
     }  // end of switch on which message 
  }  // end of ShowMessage

  
// if signature found in above table, this is its index
int foundSig = -1;
byte lastAddressMSB = 0;
// copy of current signature entry for matching processor
signatureType currentSignature;

// execute one programming instruction ... b1 is command, b2, b3, b4 are arguments
//  processor may return a result on the 4th transfer, this is returned.
byte program (const byte b1, const byte b2 = 0, const byte b3 = 0, const byte b4 = 0)
  {
  noInterrupts ();
  SPI.transfer (b1);
  SPI.transfer (b2);
  SPI.transfer (b3);
  byte b = SPI.transfer (b4);
  interrupts ();
  return b;
  } // end of program



// read a byte from flash memory
byte readFlash (unsigned long addr)
  {
  byte high = (addr & 1) ? 0x08 : 0;  // set if high byte wanted
  addr >>= 1;  // turn into word address

  // set the extended (most significant) address byte if necessary
  byte MSB = (addr >> 16) & 0xFF;
  if (MSB != lastAddressMSB)
    {
    program (loadExtendedAddressByte, 0, MSB); 
    lastAddressMSB = MSB;
    }  // end if different MSB

  return program (readProgramMemory | high, highByte (addr), lowByte (addr));
  } // end of readFlash
  
// write a byte to the flash memory buffer (ready for committing)
void writeFlash (unsigned long addr, const byte data)
  {
  byte high = (addr & 1) ? 0x08 : 0;  // set if high byte wanted
  addr >>= 1;  // turn into word address
  program (loadProgramMemory | high, 0, lowByte (addr), data);
  } // end of writeFlash  
      
   
// convert two hex characters into a byte
//    returns true if error, false if OK
bool hexConv (const char * (& pStr), byte & b)
  {

  if (!isxdigit (pStr [0]) || !isxdigit (pStr [1]))
    {
    ShowMessage (MSG_INVALID_HEX_DIGITS);
    return true;
    } // end not hex
  
  b = *pStr++ - '0';
  if (b > 9)
    b -= 7;
  
  // high-order nybble
  b <<= 4;
  
  byte b1 = *pStr++ - '0';
  if (b1 > 9)
    b1 -= 7;
    
  b |= b1;
  
  return false;  // OK
  }  // end of hexConv

// poll the target device until it is ready to be programmed
void pollUntilReady ()
  {
  if (currentSignature.timedWrites)
    delay (10);  // at least 2 x WD_FLASH which is 4.5 mS
  else
    {  
    while ((program (pollReady) & 1) == 1)
      {}  // wait till ready  
    }  // end of if
  }  // end of pollUntilReady


unsigned long pagesize;
unsigned long pagemask;
unsigned long oldPage;

// shows progress, toggles working LED
void showProgress ()
  {
        
  }  // end of showProgress
  
// clear entire temporary page to 0xFF in case we don't write to all of it 
void clearPage ()
{
  unsigned int len = currentSignature.pageSize;
  for (unsigned int i = 0; i < len; i++)
    writeFlash (i, 0xFF);
}  // end of clearPage
  
// commit page to flash memory
void commitPage (unsigned long addr)
  {
  addr >>= 1;  // turn into word address
  
  // set the extended (most significant) address byte if necessary
  byte MSB = (addr >> 16) & 0xFF;
  if (MSB != lastAddressMSB)
    {
    program (loadExtendedAddressByte, 0, MSB); 
    lastAddressMSB = MSB;
    }  // end if different MSB
    
  showProgress ();
  
  program (writeProgramMemory, highByte (addr), lowByte (addr));
  pollUntilReady (); 
  
  clearPage();  // clear ready for next page full
  }  // end of commitPage
 
// write data to temporary buffer, ready for committing  
void writeData (const unsigned long addr, const byte * pData, const int length)
  {
  // write each byte
  for (int i = 0; i < length; i++)
    {
    unsigned long thisPage = (addr + i) & pagemask;
    // page changed? commit old one
    if (thisPage != oldPage && oldPage != NO_PAGE)
      commitPage (oldPage);
    // now this is the current page
    oldPage = thisPage;
    // put byte into work buffer
    writeFlash (addr + i, pData [i]);
    }  // end of for
    
  }  // end of writeData
  
// count errors
unsigned int errors;

  
void verifyData (const unsigned long addr, const byte * pData, const int length)
  {
  // check each byte
  for (int i = 0; i < length; i++)
    {
    unsigned long thisPage = (addr + i) & pagemask;
    // page changed? show progress
    if (thisPage != oldPage && oldPage != NO_PAGE)
      showProgress ();
    // now this is the current page
    oldPage = thisPage;
      
    byte found = readFlash (addr + i);
    byte expected = pData [i];
    if (found != expected)
      errors++;
    }  // end of for
    
  }  // end of verifyData
  
bool gotEndOfFile;
unsigned long extendedAddress;

unsigned long lowestAddress;
unsigned long highestAddress;
unsigned long bytesWritten;
unsigned int lineCount;

/*
Line format:

  :nnaaaatt(data)ss
  
  Where:
  :      = a colon
  
  (All of below in hex format)
  
  nn     = length of data part
  aaaa   = address (eg. where to write data)
  tt     = transaction type
           00 = data
           01 = end of file
           02 = extended segment address (changes high-order byte of the address)
           03 = start segment address *
           04 = linear address *
           05 = start linear address *
  (data) = variable length data
  ss     = sumcheck

            * We don't use these
   
*/

// returns true if error, false if OK
bool processLine (const char * pLine, const byte action)
  {
  if (*pLine++ != ':')
     {
     ShowMessage (MSG_LINE_DOES_NOT_START_WITH_COLON);
     return true;  // error
     } 
  
  const int maxHexData = 40;
  byte hexBuffer [maxHexData];
  int bytesInLine = 0;
  
  if (action == checkFile){
    if (lineCount++ % 40 == 0){
      showProgress ();
    }
  }
    
  // convert entire line from ASCII into binary
  while (isxdigit (*pLine))
    {
    // can't fit?
    if (bytesInLine >= maxHexData)
      {
      ShowMessage (MSG_LINE_TOO_LONG);
      return true;
      } // end if too long
      
    if (hexConv (pLine, hexBuffer [bytesInLine++]))
      return true;
    }  // end of while
    
  if (bytesInLine < 5)
    {
    ShowMessage (MSG_LINE_TOO_SHORT);
    return true;  
    } 

  // sumcheck it
  
  byte sumCheck = 0;
  for (int i = 0; i < (bytesInLine - 1); i++)
    sumCheck += hexBuffer [i];
    
  // 2's complement
  sumCheck = ~sumCheck + 1;
  
  // check sumcheck
  if (sumCheck != hexBuffer [bytesInLine - 1])
    {
    ShowMessage (MSG_BAD_SUMCHECK);
    return true;
    }
  
  // length of data (eg. how much to write to memory)
  byte len = hexBuffer [0];
  
  // the data length should be the number of bytes, less
  //   length / address (2) / transaction type / sumcheck
  if (len != (bytesInLine - 5))
    {
    ShowMessage (MSG_LINE_NOT_EXPECTED_LENGTH);
    return true;
    }
    
  // two bytes of address
  unsigned long addrH = hexBuffer [1];
  unsigned long addrL = hexBuffer [2];
  
  unsigned long addr = addrL | (addrH << 8);
  
  byte recType = hexBuffer [3];

  switch (recType)
    {
    // stuff to be written to memory
    case hexDataRecord:
      lowestAddress  = min (lowestAddress, addr + extendedAddress);
      highestAddress = max (lowestAddress, addr + extendedAddress + len - 1);
      bytesWritten += len;
    
      switch (action)
        {
        case checkFile:  // nothing much to do, we do the checks anyway
          break;
          
        case verifyFlash:
          verifyData (addr + extendedAddress, &hexBuffer [4], len);
          break;
        
        case writeToFlash:
          writeData (addr + extendedAddress, &hexBuffer [4], len);
          break;      
        } // end of switch on action
      break;
  
    // end of data
    case hexEndOfFile:
      gotEndOfFile = true;
      break;
  
    // we are setting the high-order byte of the address
    case hexExtendedSegmentAddressRecord: 
      extendedAddress = ((unsigned long) hexBuffer [4]) << 12;
      break;
      
    // ignore these, who cares?
    case hexStartSegmentAddressRecord:
    case hexExtendedLinearAddressRecord:
    case hexStartLinearAddressRecord:
      break;
        
    default:  
      ShowMessage (MSG_UNKNOWN_RECORD_TYPE);
      return true;  
    }  // end of switch on recType
    
  return false;
  } // end of processLine

//------------------------------------------------------------------------------
// returns true if error, false if OK
bool readHexFile (const byte action)
  {
  const int maxLine = 80;
  char buffer [80];
  
  int lineNumber = 0;
  gotEndOfFile = false;
  extendedAddress = 0;
  errors = 0;
  lowestAddress = 0xFFFFFFFF;
  highestAddress = 0;
  bytesWritten = 0;

  pagesize = currentSignature.pageSize;
  pagemask = ~(pagesize - 1);
  oldPage = NO_PAGE;
  
  ifstream sdin (selectedHexFile); 
   
  // check for open error
  if (!sdin.is_open()) 
  {
    ShowMessage (MSG_CANNOT_OPEN_FILE);
    return true;
  }
    
  switch (action)
    {
    case checkFile:
      break;
      
    case verifyFlash:
      break;
    
    case writeToFlash:
      program (progamEnable, chipErase);   // erase it
      delay (20);  // for Atmega8
      pollUntilReady (); 
      clearPage();  // clear temporary page
      break;      
    } // end of switch

    while (sdin.getline (buffer, maxLine))
    {
    lineNumber++;
    int count = sdin.gcount();
    if (sdin.fail()) 
      {
      ShowMessage (MSG_LINE_TOO_LONG);
      return true;
      }  // end of fail (line too long?)
      
    // ignore empty lines
    if (count > 1)
      {
      if (processLine (buffer, action))
        {
        return true;  // error
        }
      }
    }    // end of while each line
    
  if (!gotEndOfFile)
    {
    ShowMessage (MSG_NO_END_OF_FILE_RECORD);
    return true;
    }

  switch (action)
    {
    case writeToFlash:
      // commit final page
      if (oldPage != NO_PAGE)
        commitPage (oldPage);
      break;
      
    case verifyFlash:
       if (errors > 0)
          {
          ShowMessage (MSG_VERIFICATION_ERROR);
          return true;
          }  // end if
       break;
        
    case checkFile:
      break;
    }  // end of switch
  
  return false;
}  // end of readHexFile


// returns true if managed to enter programming mode
bool startProgramming ()
  {

  byte confirm;
  pinMode (RESET, OUTPUT);
  digitalWrite (RESET, HIGH);  // ensure SS stays high for now
  SPI.begin ();
  SPI.setClockDivider (SPI_CLOCK_DIV64);
  pinMode (SCK, OUTPUT);
  
  unsigned int timeout = 0;
  
  // we are in sync if we get back programAcknowledge on the third byte
  do 
    {
    // regrouping pause
    delay (100);

    // ensure SCK low
    noInterrupts ();
    digitalWrite (MSPIM_SCK, LOW);
    // then pulse reset, see page 309 of datasheet
    digitalWrite (RESET, HIGH);
    delayMicroseconds (10);  // pulse for at least 2 clock cycles
    digitalWrite (RESET, LOW);
    interrupts ();

    delay (25);  // wait at least 20 mS
    noInterrupts ();
    SPI.transfer (progamEnable);  
    SPI.transfer (programAcknowledge);  
    confirm = SPI.transfer (0);  
    SPI.transfer (0);  
    interrupts ();
    
    if (confirm != programAcknowledge)
      {
      if (timeout++ >= ENTER_PROGRAMMING_ATTEMPTS){
          return false;
        }
      }  // end of not entered programming mode
    
    } while (confirm != programAcknowledge);
  return true;  // entered programming mode OK
}  // end of startProgramming

void stopProgramming ()
  {
    
  digitalWrite (RESET, LOW);
  pinMode (RESET, INPUT);
  SPI.end ();
    
  } // end of stopProgramming
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
void loop () 
{
  int x;
  x = analogRead (JOYSTICK_KEY);

  // DIRTY HACK, because pull-up was missing and first\imidiate read is "0" and triggeres the action with no good reason (probably very low SRAM)
  delay(10);
  x = analogRead (JOYSTICK_KEY); 
  
  Serial.println(x);
  
  if ((x < 100) & (keydown==0)) {
    // Select
    keydown=1;
                                    // Note the syntax for doing this
    doWork(menu_select);

    delay(100);
    tftMenuInit();                  // Redraw the Menu
    tftMenuSelect(menu_select);     // Highlight the current menu item
  }
  else if ((x < 200) & (keydown==0)){
    // Down
    // move down one menu item, if at bottom wrap to top
    keydown=1;    
    if (menu_select<numMenu) tftMenuSelect(menu_select+1);
    else tftMenuSelect(1);   
  }
  else if ((x < 400) & (keydown==0)){
    // Right
    keydown=1;    
  }  
   else if ((x < 550) & (keydown==0)) {
    // Up
    // move up one menu item, if at top wrap to bottom
    keydown=1;    
    if (menu_select>1) tftMenuSelect(menu_select-1);
    else tftMenuSelect(numMenu);
  }
  else if ((x < 800) & (keydown==0)){
    // Left
    keydown=1;    
  }
  else if (x >= 800)
  {
    keydown=0; // key released
  }

  // A and B buttons 

  // "A" switch not in use at the moment
  
  int switchAState = 0;
  switchAState = digitalRead(switchA);

  if (switchAState == LOW) {
    // Burn bootloader
  }
  /**/

  int switchBState = 0;
  switchBState = digitalRead(switchB);
  
  if (switchBState == LOW) {
    // Backup current target MCU firmware  
    //--------
    tft.fillScreen(ST7735_BLACK);  
    delay(50);
    displayText(F("CREATING BACKUP,\nPLEASE WAIT!"), ST7735_YELLOW);
    
    readFlashContents();
    
    delay(100);
    tftMenuInit();                  // Redraw the Menu
    tftMenuSelect(menu_select); 
    /*
    Serial.print(F( "debug: Free ram = " ) );
    Serial.println( freeMemory() ) ;
    Serial.flush() ;
    */
  }
}  // end of loop

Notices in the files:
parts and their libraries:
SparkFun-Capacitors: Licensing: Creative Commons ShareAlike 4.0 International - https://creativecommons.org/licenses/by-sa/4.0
